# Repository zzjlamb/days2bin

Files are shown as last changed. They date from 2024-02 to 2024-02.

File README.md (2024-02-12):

# Days2Bin

An indicator to show number of days until different kerbside
bins/trash/recycling etc are due to be collected.

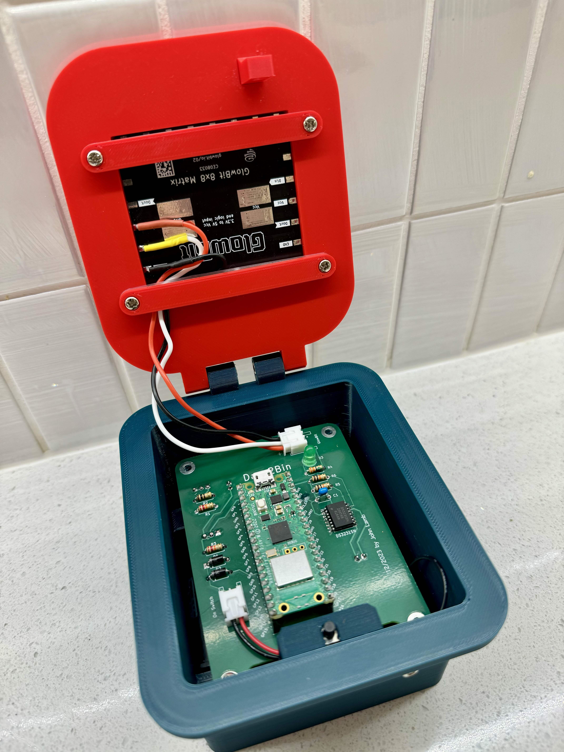
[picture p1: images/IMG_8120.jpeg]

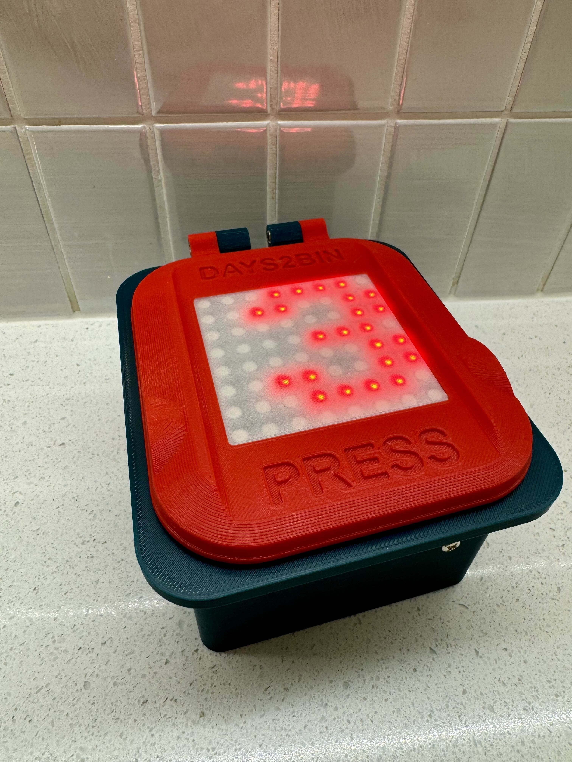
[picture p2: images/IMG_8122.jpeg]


## Hardware

Raspberry Pi Pico W, DS3231 RTC and
Core Electronics GlowBit (based on WS2812 addressable LEDs).
 
The device is powered by 3 x AAA batteries switched by a pair of logic level MOSFETs
triggered by grounding via a momentary pushbutton, then kept alive
by one of the Pico W GPIO's until the Pico logic shuts it down.

A separate pair of AAA batteries powers the DS3231 RTC. I try to avoid button batteries for child safety reasons. These should last much longer than the main batteries due to the very low current drain of the DS3231, and having them saves having to re-enter the time.

The settings are stored in a dedicated page of flash, which is reserved by a custom loader script.

Settings are entered by holding the pushbutton down until a Wifi symbol is displayed, and joining the Days2Bin wifi access point. Apple devices should then display the settings page via captive portal. Other devices can display the page by browsing to http://192.168.4.1 after joining the access point.

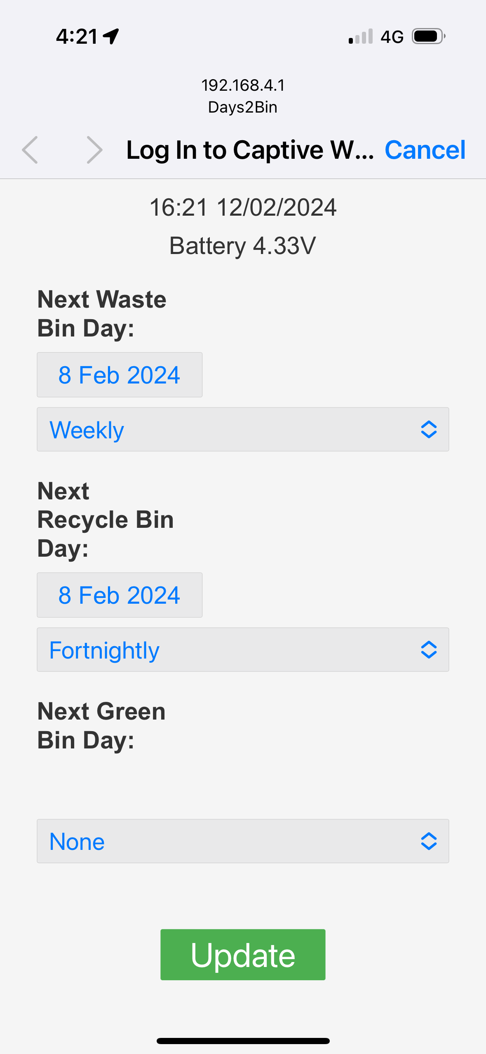
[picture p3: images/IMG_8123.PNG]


Up to three bins can be configured: general waste, recyling, and green waste. The device scrolls the number of days to each type in red, yellow and green colours respectively, then powers off, unless the button is held on, in which case Settings mode is entered.

On first use, or if the clock battery has failed, users are prompted to join the access point.

Time out for the access point is 2 minutes.

This project was coded entirely in C using the Pico SDK. I originally tried to code it in MicroPython, however the startup time was several seconds, whereas the C version is virtually instantaneous.

2024 by John Lamb
Licenced under MIT Licence

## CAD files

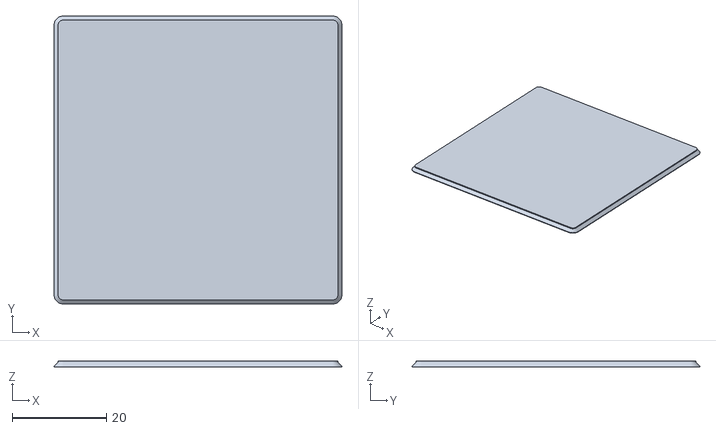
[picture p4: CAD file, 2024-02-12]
3DModels/WheelieBin-Diffuser0p15_layer_ht.obj
61.2 x 61.2 x 1.30

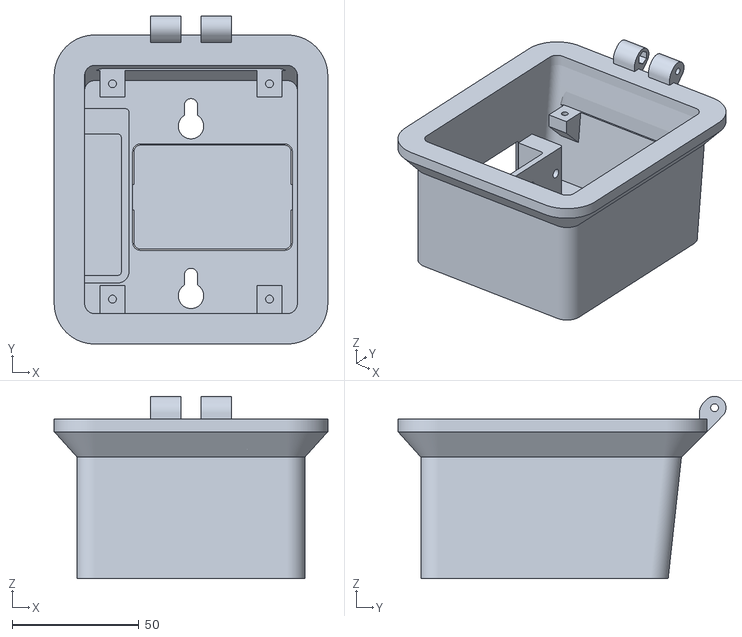
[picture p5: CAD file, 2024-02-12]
3DModels/Bin.stl
108.0 x 129.5 x 72.0

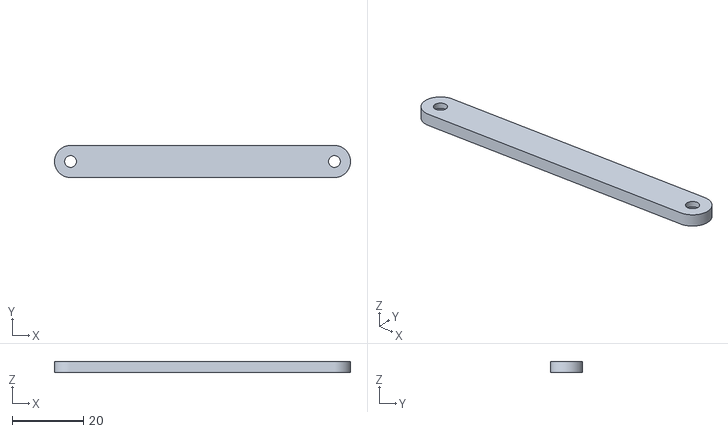
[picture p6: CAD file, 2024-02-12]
3DModels/WheelieBin-HardPCBHolder.obj
83.0 x 9.00 x 3.00

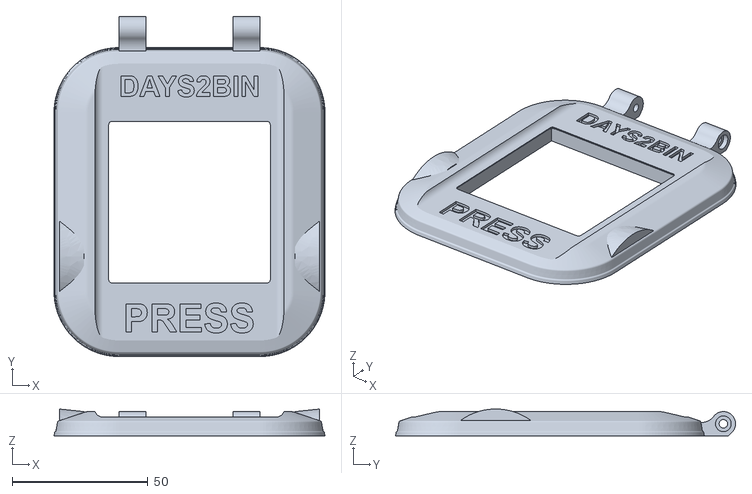
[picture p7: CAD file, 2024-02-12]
3DModels/WheelieBin-Lid.obj
100.0 x 125.5 x 9.95

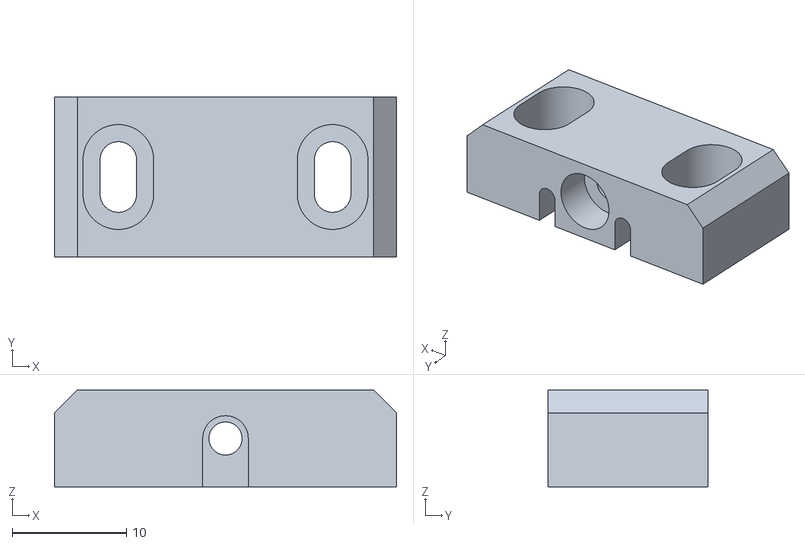
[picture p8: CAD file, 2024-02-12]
3DModels/PushbuttonHolder.stl
30.0 x 14.0 x 8.50

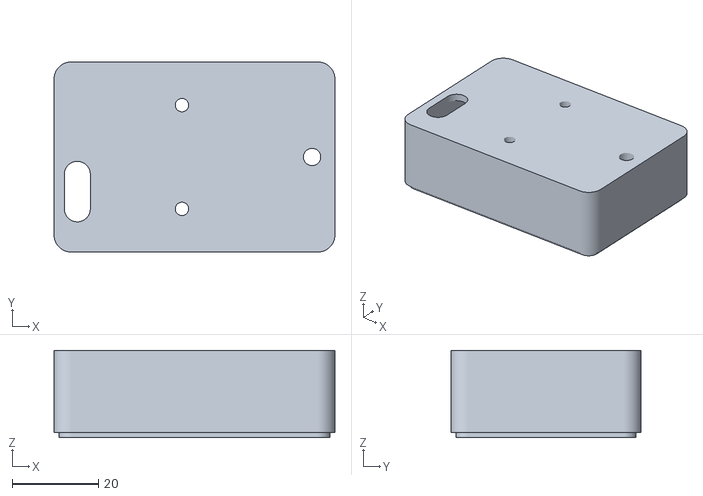
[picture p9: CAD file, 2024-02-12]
3DModels/AAAx3 Battery Case.stl
65.0 x 44.0 x 20.2

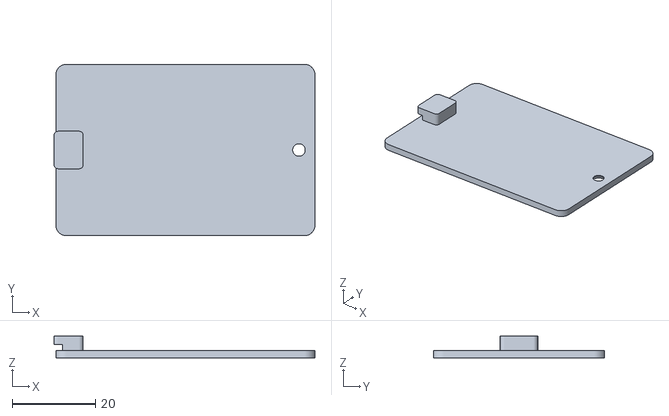
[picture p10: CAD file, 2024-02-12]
3DModels/AAAx3 Battery Cover.stl
62.5 x 41.1 x 5.20

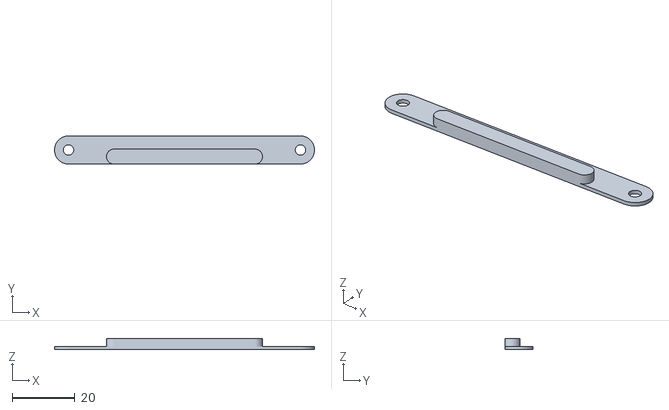
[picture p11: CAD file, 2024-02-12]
3DModels/WheelieBin-SoftPCBHolder.obj
83.0 x 9.00 x 3.60

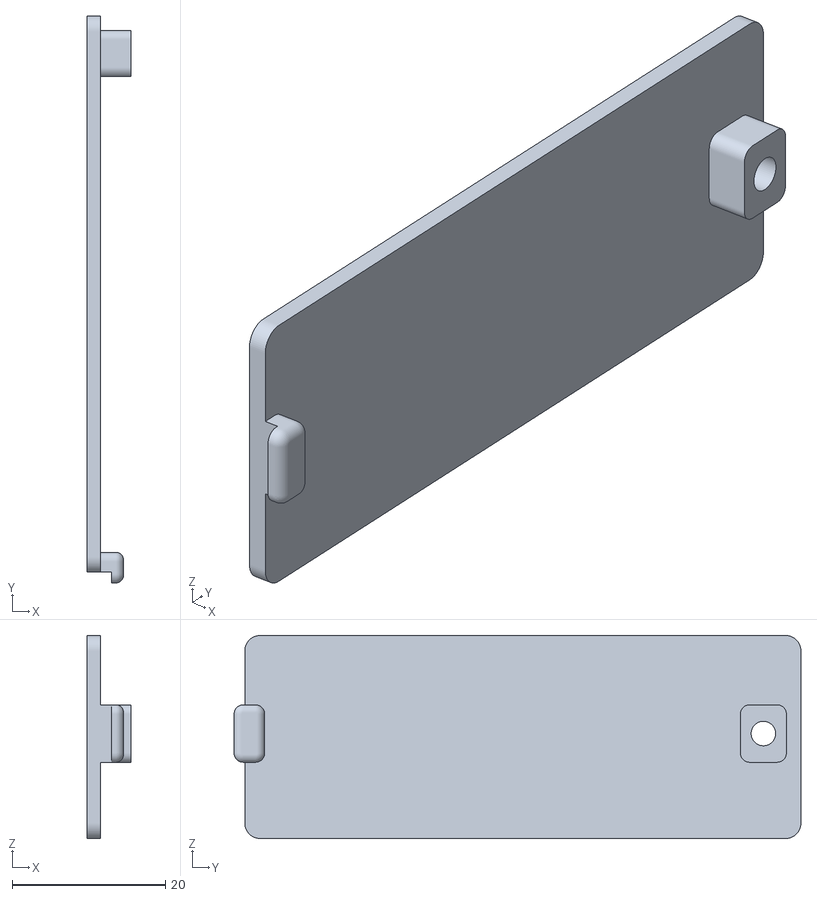
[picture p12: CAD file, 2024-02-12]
3DModels/AAAx2Cover.stl
5.80 x 74.0 x 26.5

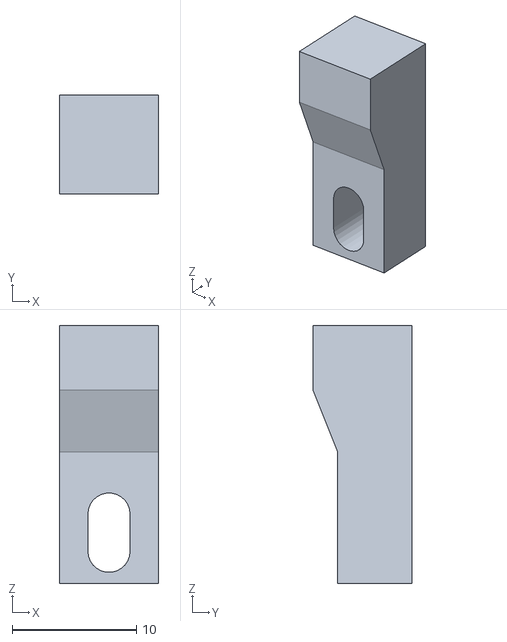
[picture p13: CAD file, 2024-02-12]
3DModels/WheelieBin-LimiterPin.obj
8.00 x 8.00 x 20.8

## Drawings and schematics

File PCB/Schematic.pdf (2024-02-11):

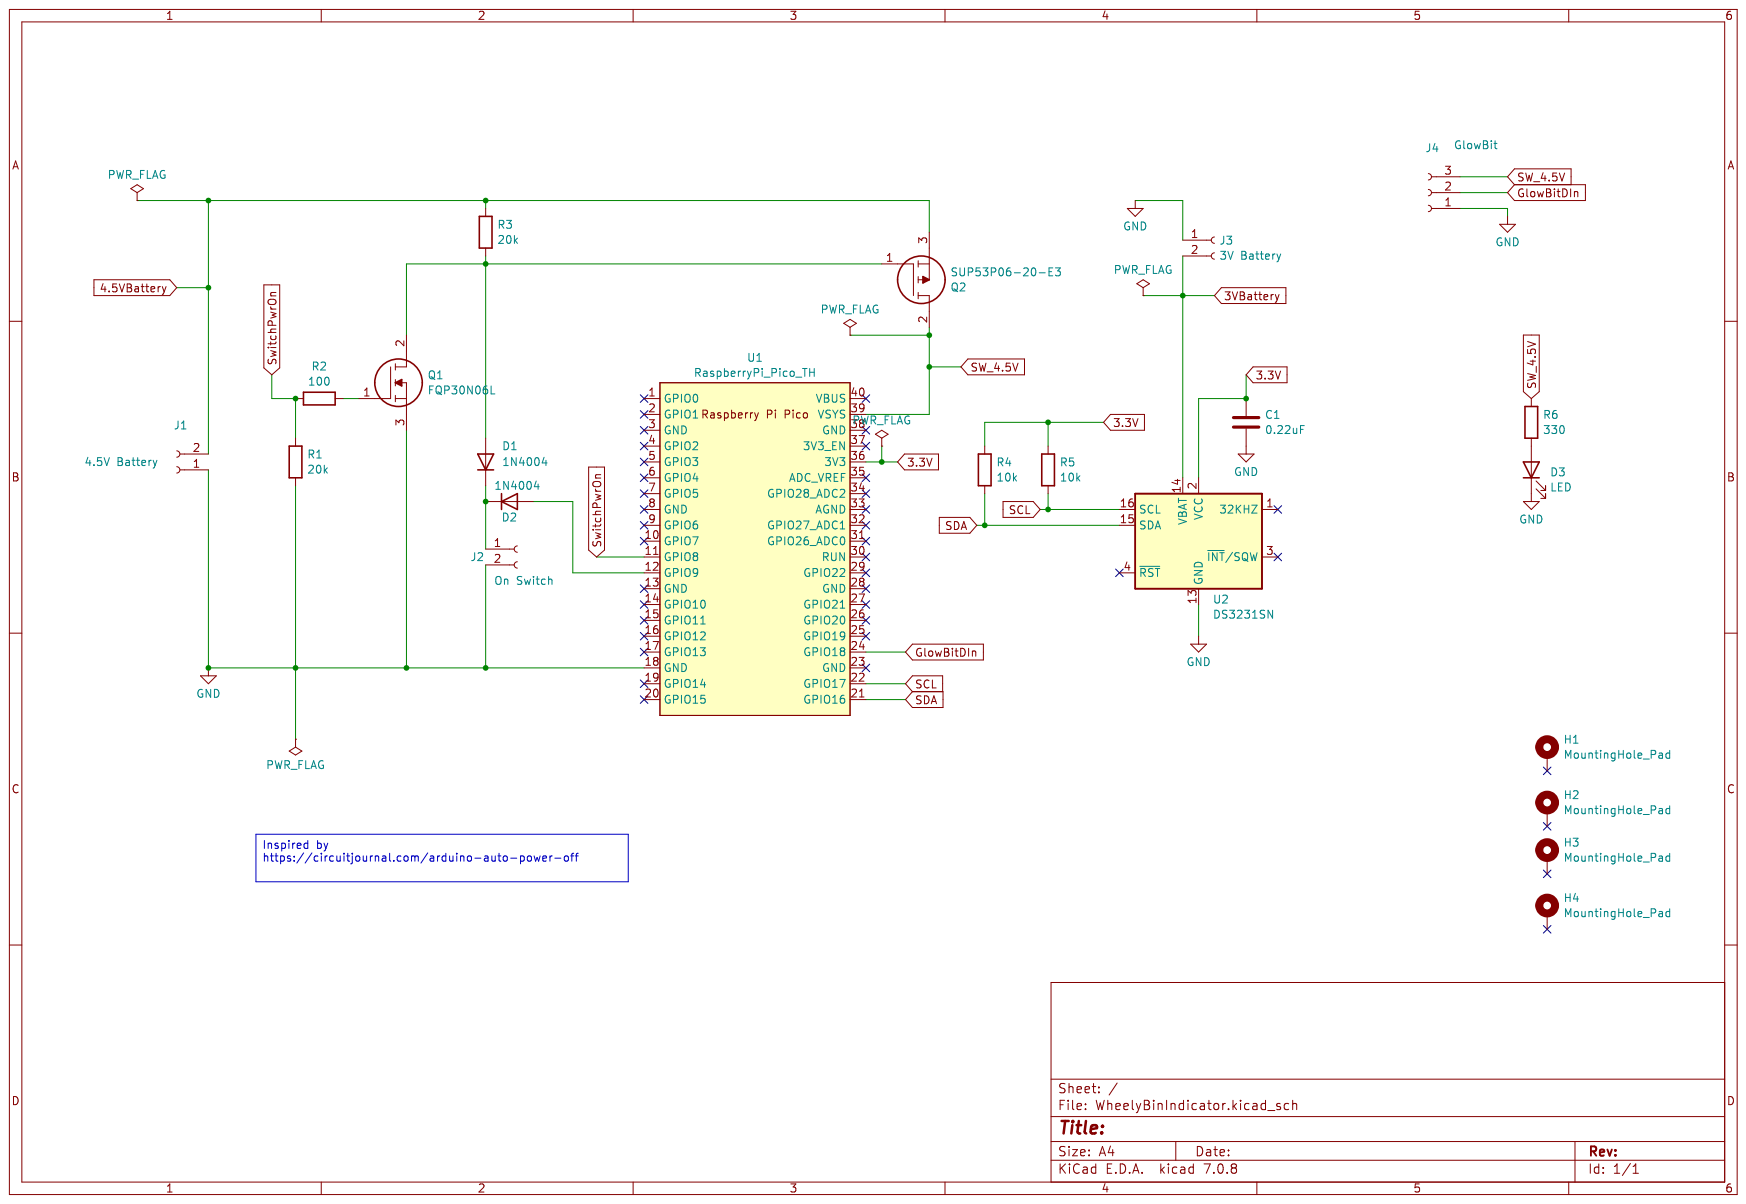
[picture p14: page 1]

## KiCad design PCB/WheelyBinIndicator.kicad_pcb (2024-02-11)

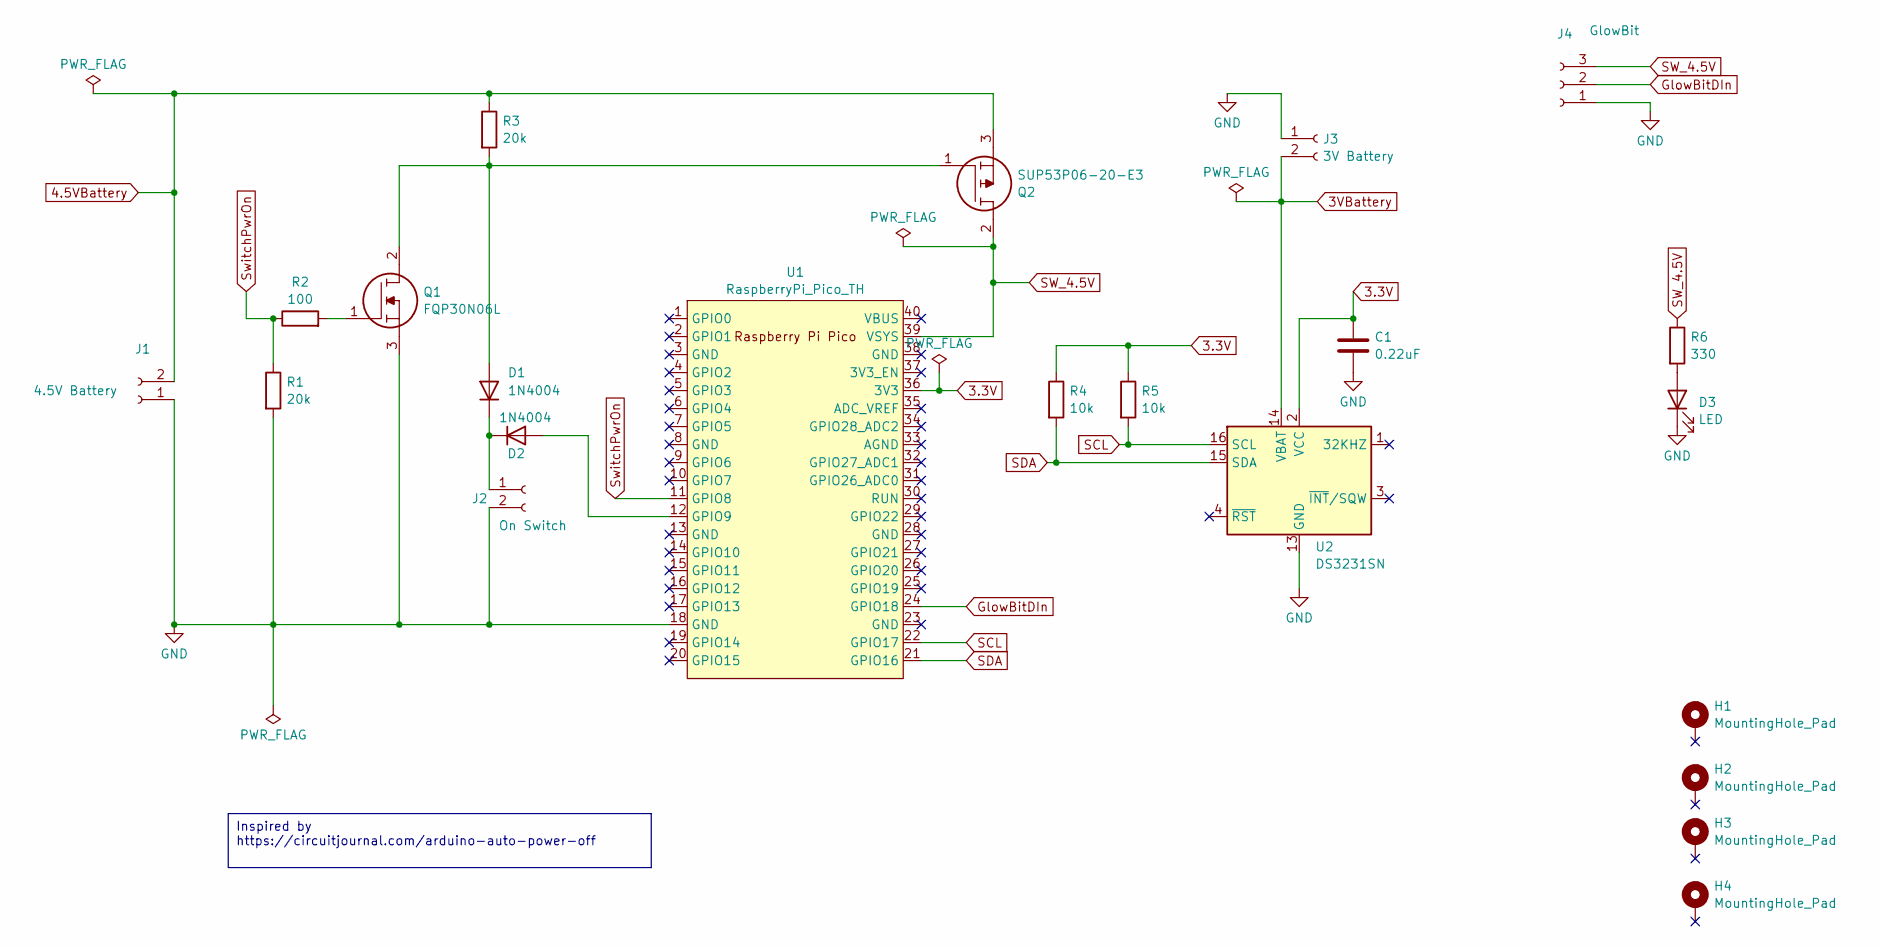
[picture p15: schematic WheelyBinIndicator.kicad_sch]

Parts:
C1: 0.22uF; C_Disc_D4.7mm_W2.5mm_P5.00mm
D1, D2: 1N4004; D_A-405_P7.62mm_Horizontal
D3: LED; LED_D5.0mm
H1, H2, H3, H4: MountingHole_Pad; MountingHole_3.2mm_M3_Pad
J1: 4.5V Battery; JST_XH_B2B-XH-A_1x02_P2.50mm_Vertical
J2: On Switch; JST_XH_S2B-XH-A-1_1x02_P2.50mm_Horizontal
J3: 3V Battery; JST_XH_B2B-XH-A_1x02_P2.50mm_Vertical
J4: GlowBit; JST_XH_S3B-XH-A-1_1x03_P2.50mm_Horizontal
Q1: FQP30N06L; TO-220-3_Vertical; Manufacturer_Part_Number FQP30N06L; Mouser Part Number 512-FQP30N06L
Q2: SUP53P06-20-E3; TO-220-3_Vertical; Manufacturer_Part_Number SUP53P06-20-E3; Mouser Part Number 781-SUP53P06-20-E3
R1, R3: 20k; R_Axial_DIN0207_L6.3mm_D2.5mm_P7.62mm_Horizontal
R2: 100; R_Axial_DIN0207_L6.3mm_D2.5mm_P7.62mm_Horizontal
R4, R5: 10k; R_Axial_DIN0207_L6.3mm_D2.5mm_P7.62mm_Horizontal
R6: 330; R_Axial_DIN0207_L6.3mm_D2.5mm_P7.62mm_Horizontal
U1: RaspberryPi_Pico_TH; RPi_Pico_TH
U2: DS3231SN; SOIC-16W_7.5x10.3mm_P1.27mm

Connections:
3.3V: C1.1, R4.1, R5.1, U1.36 (3V3), U2.2 (VCC)
3VBattery: J3.2, U2.14 (VBAT)
4.5VBattery: J1.2, Q2.3, R3.1
GND: C1.2, D3.1 (K), J1.1, J2.2, J3.1, J4.1, Q1.3, R1.2, U1.18 (GND), U2.5 (GND), U2.6 (GND), U2.7 (GND), U2.8 (GND), U2.9 (GND), U2.10 (GND), U2.11 (GND), U2.12 (GND), U2.13 (GND)
GlowBitDIn: J4.2, U1.24 (GPIO18)
unnamed: D1.2 (A), Q1.2, Q2.1, R3.2
unnamed: D1.1 (K), D2.1 (K), J2.1
unnamed: D2.2 (A), U1.12 (GPIO9)
unnamed: D3.2 (A), R6.2
unnamed: Q1.1, R2.2
SCL: R5.2, U1.22 (GPIO17), U2.16 (SCL)
SDA: R4.2, U1.21 (GPIO16), U2.15 (SDA)
SW_4.5V: J4.3, Q2.2, R6.1, U1.39 (VSYS)
SwitchPwrOn: R1.1, R2.1, U1.11 (GPIO8)

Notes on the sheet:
Inspired by https://circuitjournal.com/arduino-auto-power-off

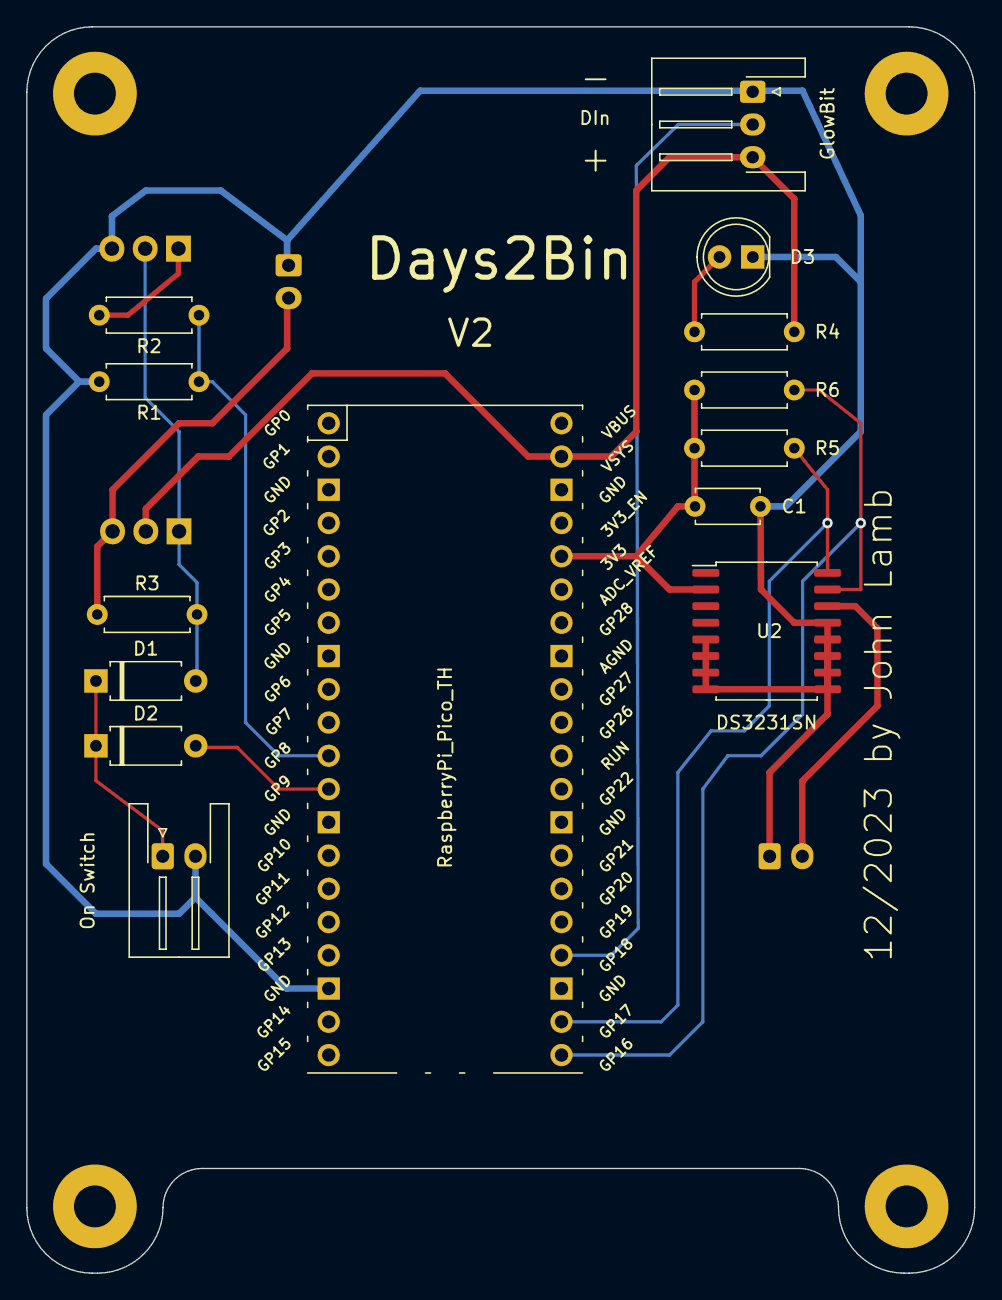
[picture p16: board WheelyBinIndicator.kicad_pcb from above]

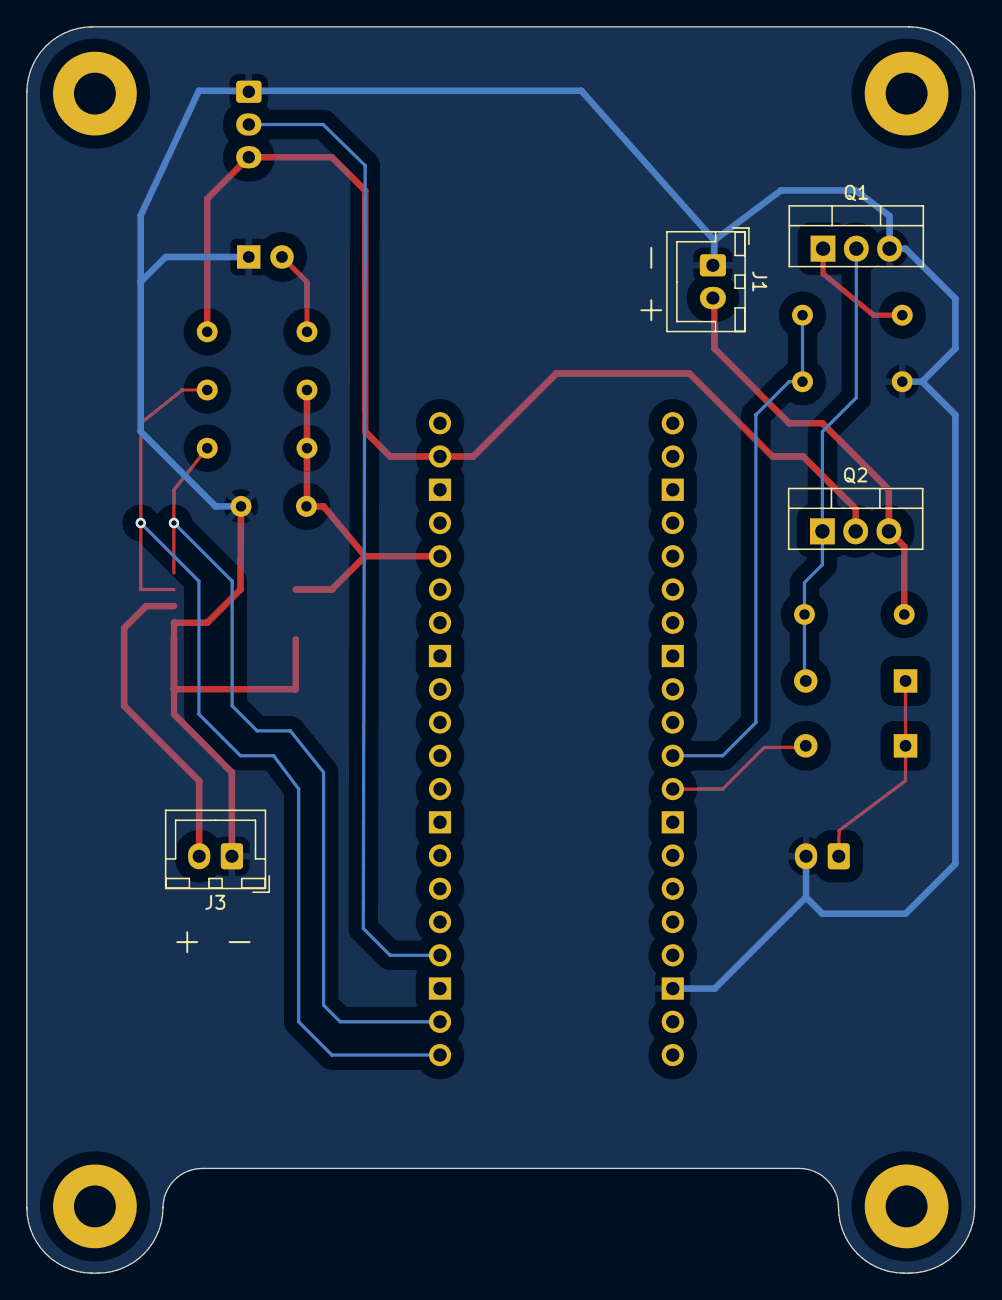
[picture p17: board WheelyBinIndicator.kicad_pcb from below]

Board: 2 copper layers, 72.4 x 95.2 mm, 22 parts (4 on the bottom side), 14 nets.

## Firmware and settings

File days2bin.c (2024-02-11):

/**
 * Days2Bin
 * An indicator to show number of days until different kerbside
 * bins/trash/recycling etc are due to be collected.
 *
 * Hardware - Raspberry Pi Pico W, DS3231 RTC and
 * Core Electronics GlowBit (based on WS2812 addressable LEDs).
 *
 * The device is powered on by a pair of logic level MOSFETs
 * triggered by grounding via a momentary pushbutton, and kept alive
 * by one of the Pico W GPIO's.
 *
 * 2024 by John Lamb
 * Licenced under MIT Licence
 */

#include <stdio.h>
#include <string.h>
#include "pico/stdlib.h"
#include "hardware/adc.h"
#include "pico/cyw43_arch.h"
#include "pico/float.h"

#include <power_status.h>

#include "flash/flash_utils.h"
#include "peripherals/glowbit.h"
#include "ds3231.h"
#include "GPIO_pin_assignments.h"
#include "peripherals/power_mgr.h"
#include "access_point.h"

/* Globals */

ds3231_t ds3231;                    // DS3231 real time clock
char batteryVoltageStr [8]={};      // Battery voltage

int main()
{
    /* First we have to take over from the pushbutton keep the PICO powered until   */ 
    /* we want to shut down.                                                        */

    power_mgr_init();

    /* Initialise coms for debug messages, and wait to stabilise   */

    stdio_init_all();
    sleep_ms(200);

    /* Initialise the ADC so we can check battery voltage */

    adc_init();

    /* Pico W uses a CYW43 pin to get VBUS so we need to initialise it.                 */
    /* The same pin is used for wi-fi so we need to check the voltage then de-init      */
    /* before the webserver runs.                                                       */

    if (!cyw43_arch_init())
    {
        // Get voltage
        float voltage;
        int voltage_return = power_voltage(&voltage);
        voltage = floorf(voltage * 100) / 100;
        snprintf(batteryVoltageStr,sizeof(batteryVoltageStr),"%.2f",voltage);
        cyw43_arch_deinit();
    }

    /* Initialise ds3231 struct. */

    ds3231_init(&ds3231, i2c_default, DS3231_DEVICE_ADRESS, AT24C32_EEPROM_ADRESS_0);
    sleep_ms(200);

    /* Initialise I2C for the DS3231. */

    gpio_init(DS3231_SDA_PIN);
    gpio_init(DS3231_SCL_PIN);
    gpio_set_function(DS3231_SDA_PIN, GPIO_FUNC_I2C);
    gpio_set_function(DS3231_SCL_PIN, GPIO_FUNC_I2C);
    gpio_pull_up(DS3231_SDA_PIN);
    gpio_pull_up(DS3231_SCL_PIN);
    i2c_init(ds3231.i2c, 400 * 1000);

    /* Initialise Glowbit matrix */

    glowbit_init();

    /* For debugging and development only */
    // make_test_data();
    // write_flash();

    /* Get a pointer to the reserved flash page where   */
    /* our settings are stored.                         */

    Bin_Info *bi = read_flash();

    /* Get the date and time from the DS3231. */

    ds3231_data_t ds3231_data = {};
    ds3231_read_current_time(&ds3231, &ds3231_data);

    if ( (bi[NUM_BIN_KINDS].interval == MAGIC_NUMBER) || (ds3231_data.year==0) )
    {
        /* Here if already set up, ie Magic number in flash, and DS3231 has a non-zero year. */ 

        int dtc[NUM_BIN_KINDS];
        getDaysToCollection(dtc, ds3231_data.century, ds3231_data.year, ds3231_data.month, ds3231_data.date);
        uint32_t binColours[] = {glowbit_RED, glowbit_YELLOW, glowbit_GREEN};
        for (int j = 0; j < 2; j++)
        {
            for (int i = 0; i < NUM_BIN_KINDS; i++)
            {
                char s[10] = {};
                sprintf(s, "%d", dtc[i]);
                uint32_t colour;
                if (dtc[i] > 0)
                    glowbit_scrollText(s, binColours[i]);
            };
        };
    }
    else
    {
        /* Here if no magic number or an invalid date, so prompt to enter set up mode           */
        /* This will occur for first time use, or if RTC battery has failed or been replaced.   */

        glowbit_scrollText("Keep pressing lid to set up ...", glowbit_BLUE);
    }

    /* Is the power on button still on?                 */
    /* If so start web server and await new settings    */ 

    if (!gpio_get(PowerOnButtonGPIO))
    {
        glowbit_scrollText("Join Days2Bin WiFi ...", glowbit_BLUE);
        glowbit_drawChar('~', glowbit_BLUE); // wifi symbol
        glowbit_show();
        access_point();
    }
    else        /* Power down */
    {
        power_mgr_shutDownNow();
    }
}

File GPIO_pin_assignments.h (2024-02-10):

#pragma once

#define PowerOnButtonGPIO 9   // Low if button pressed
#define DS3231_SDA_PIN 16     // I2C SDA
#define DS3231_SCL_PIN 17     // I2C SCL
#define WS2812_PIN 18         // GPIO connected to Glowbit DIN terminal
#define stay_powered_on_PIN 8 // high to keep MOSFETs switched on, low to turn self off

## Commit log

2024-01-02 glowbit working, with I2c scan now too
2024-01-12 DS3231.cpp-> DS3231_new.cpp to change I2C pins
2024-02-10 Working pus batt voltage/temp
2024-02-10 Added battery voltage
2024-02-11 PCB added
    [WheelyBinIndicator.kicad_pcb, WheelyBinIndicator.kicad_sch]
2024-02-11 Schematic.pdf added
2024-02-12 3D Models added
    [AAAx2Cover.stl, AAAx3 Battery Case.stl, AAAx3 Battery Cover.stl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]
